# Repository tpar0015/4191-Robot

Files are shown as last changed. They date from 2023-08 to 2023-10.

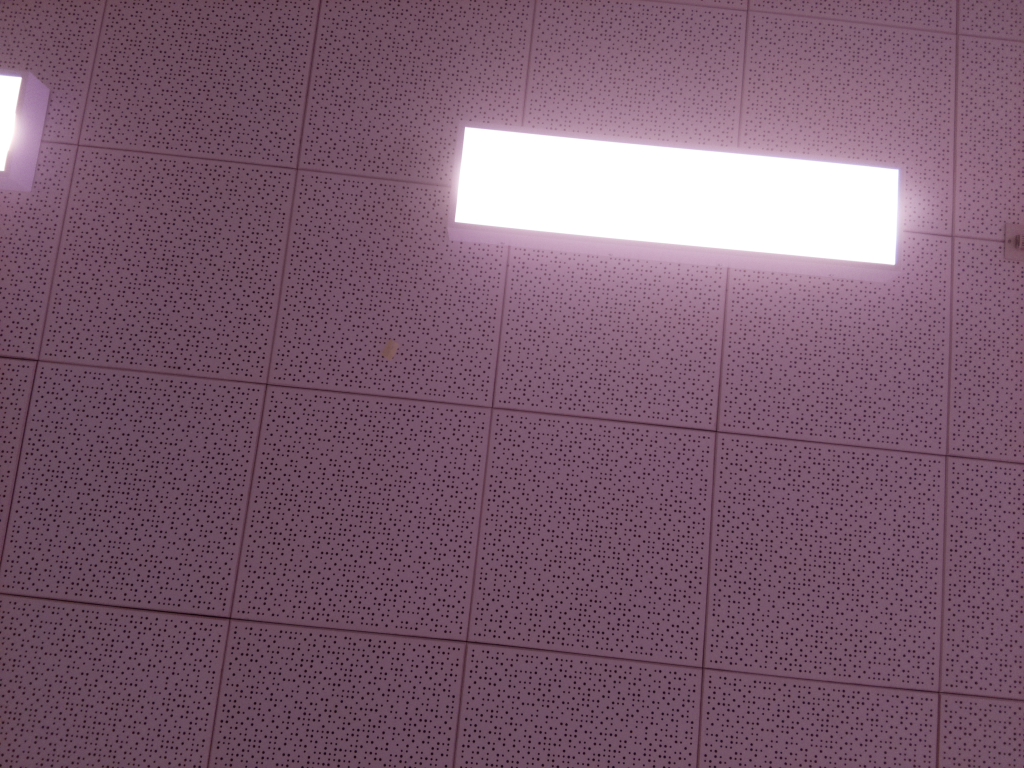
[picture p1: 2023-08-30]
camera_img/camera4.jpg

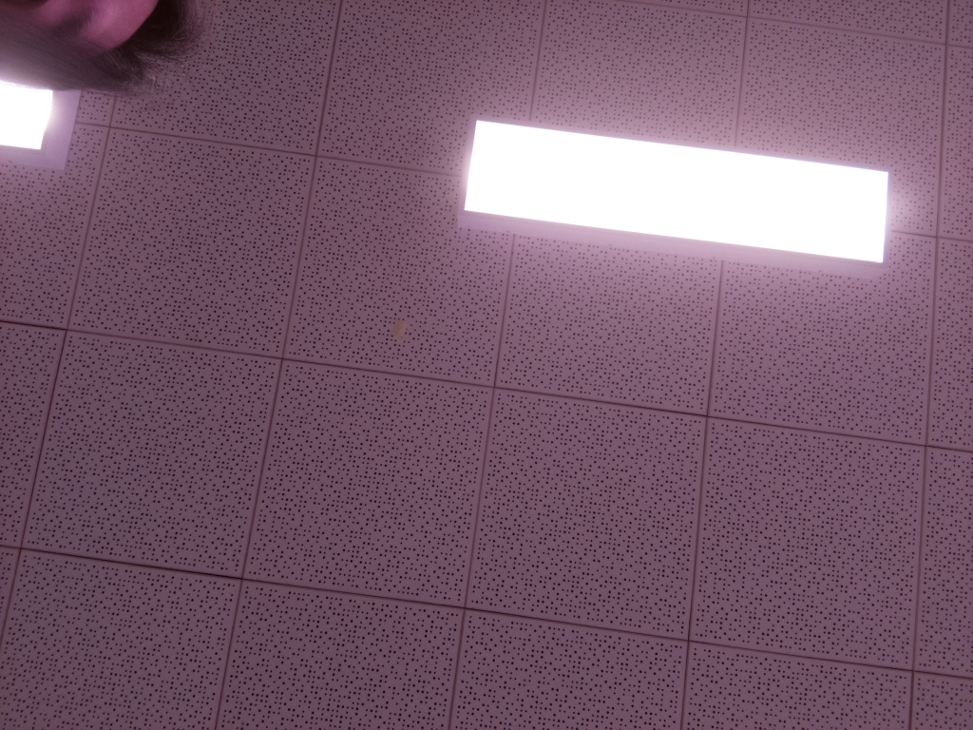
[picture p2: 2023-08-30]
camera_img/camera1.jpg

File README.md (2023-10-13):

# 4191-Robot

## Running loop

### 1. Load package

Robot should be in a safe state.

Needs to detect when package is loaded

### 2. Find target

Check sensors, apply computer vision if necessary.

Determine coordinates in warehouse.
    Possible method: find corners of the warehouse, centre for B and some angle for A/C. This relies on accuracy of robot placement and placement of bins

### 3. Aim

a. Aim horizontal

~~b. Aim vertical~~

c. Determine launch velocity

(confirm by checking sensors that target is centred)

### 4. Fire

Shoot projectile with predetermined parameters

### 5. Reset

Return to safe state

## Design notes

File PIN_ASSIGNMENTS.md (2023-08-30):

# Pin assignments

## Motors
BCM -- BOARD pin numbers
### Right motor
Fwd: 12 -- 32
Rev: 16 -- 36
EN: 6 -- 31

### Left motor
Fwd: 18 -- 12
Rev: 22 -- 15
EN: 27 -- 13

## Ultrasonic
Trig pin: 17
Echo pin: 20

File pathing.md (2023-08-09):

# 1. Localisation (localisation.py)

1. Consider immediately previous event.
    * Driving? Then robot is in middle of arena
    * Picked up box? Then robot is in the loading zone
    * Just delivered box? Then robot is in the delivery zone near A/B/C

2. Check sensor data

3. Convert sensor data to X,Y

4. Run navigation.py

# 2. Navigation (navigation.py)

0. Set up array of legal nodes (that are within the arena and NOT near any obstacles)

1. Check target destination
    * What's on the box? A/B/C

2. Check current location

3. Get target location

4. Run Dijkstra's algorithm

5. Run motor control
    * Generate motor inputs, pass to motorctl.py

6. IF arrived at delivery location, run loading.py
    * Pass LOAD or UNLOAD

# 3. Motor Control (motorctl.py) 

1. Get motor inputs

2. Translate to duty cycle for PWM

3. Apply to pins

# 4. Pickup/Delivery (loading.py)

0. If passed UNLOAD, goto 1; else if passed LOAD, goto 2

1. Unload
    * Turn toward wall
    * Tip out tray

2. Load
    * Turn away from wall
    * Raise tray

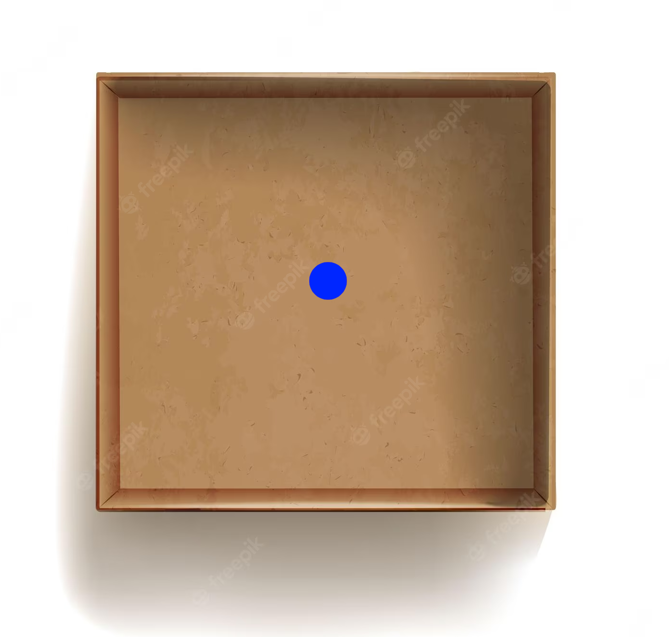
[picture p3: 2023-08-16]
package_detection/Blue/blue.png

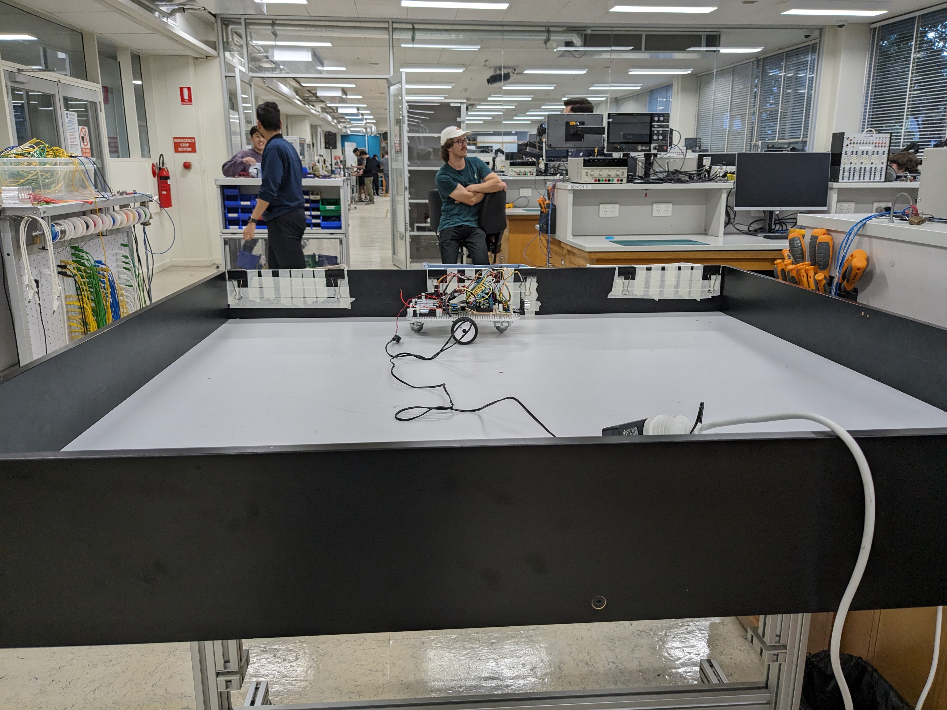
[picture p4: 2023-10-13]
Corner Detection/arena_tape_robot.jpg

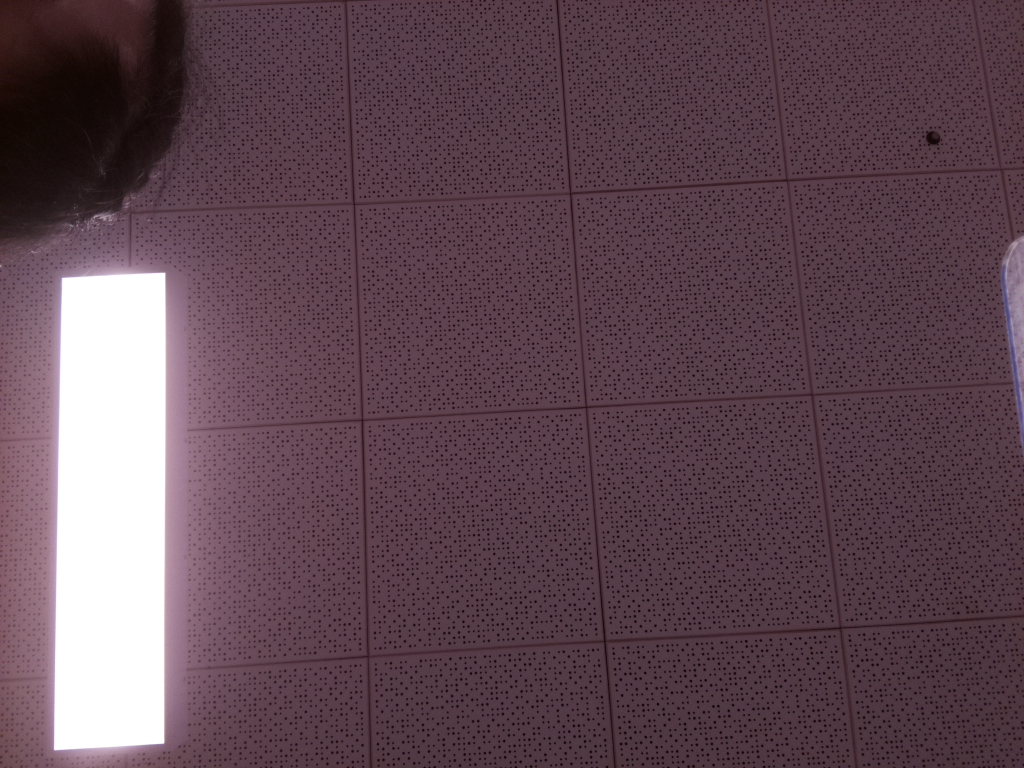
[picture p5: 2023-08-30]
camera_img/tes2/camera5.jpg

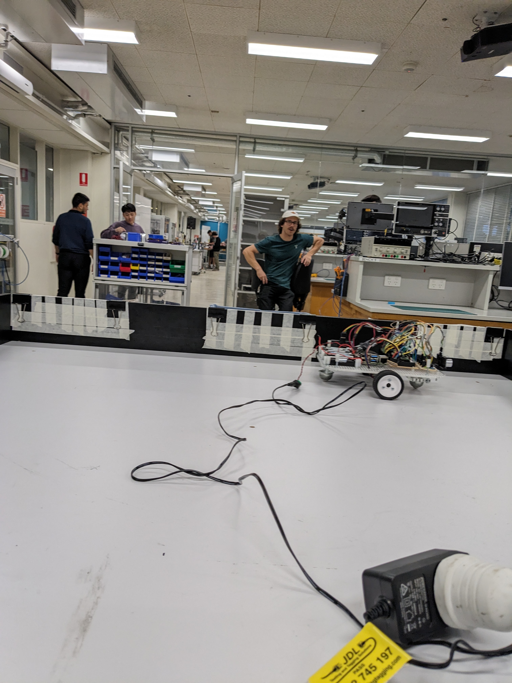
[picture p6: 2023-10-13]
Corner Detection/arena_tape_robot2.jpg

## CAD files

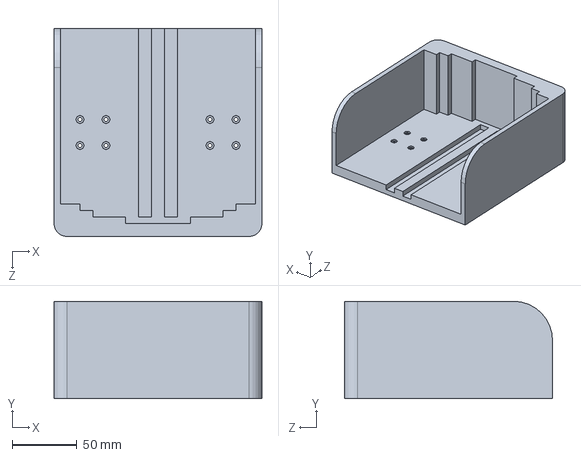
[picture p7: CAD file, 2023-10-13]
models/Drawback Assembly/package holder.SLDPRT
160.0 x 75.0 x 160.0 mm

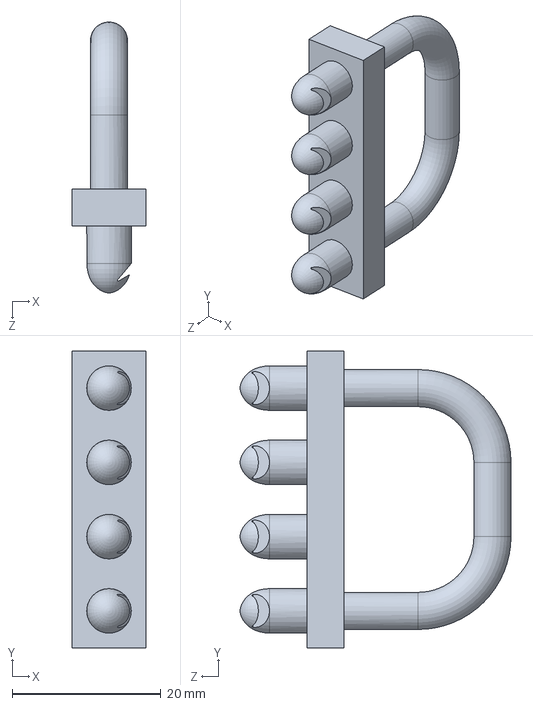
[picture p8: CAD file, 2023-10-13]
models/spring hook.SLDPRT
10.0 x 40.0 x 36.5 mm

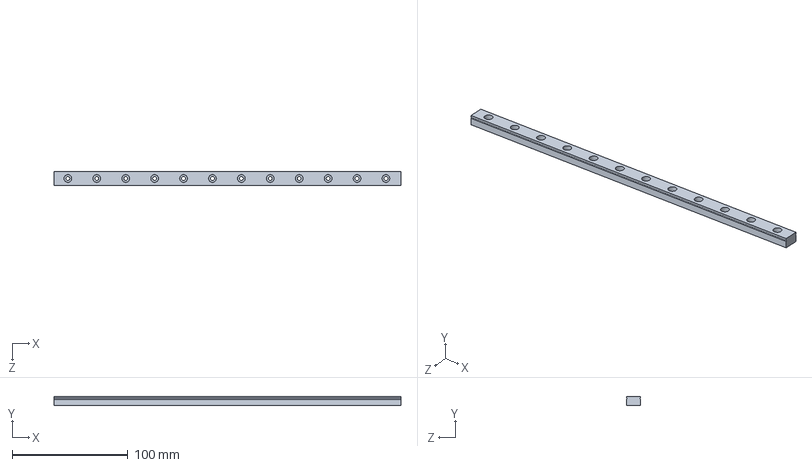
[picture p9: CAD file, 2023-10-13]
models/Drawback Assembly/linear_rail.SLDPRT
300.0 x 8.00 x 12.0 mm

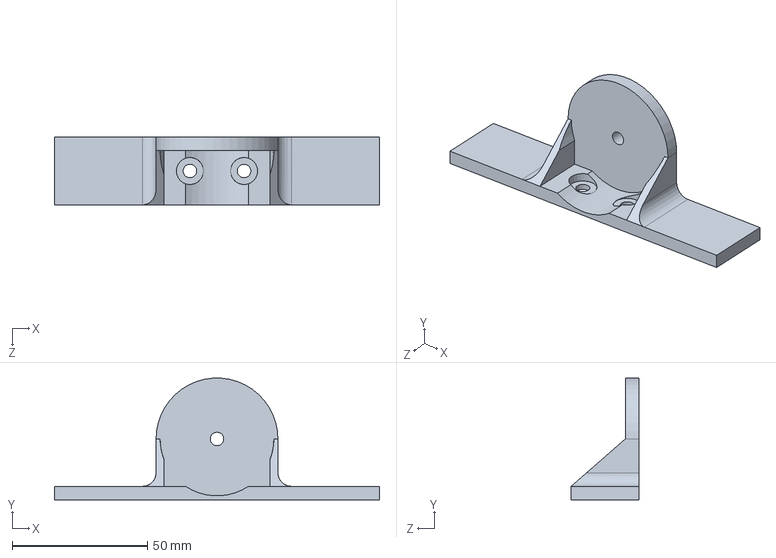
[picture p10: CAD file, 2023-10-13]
models/electromagnet holder.SLDPRT
120.0 x 44.9 x 25.0 mm

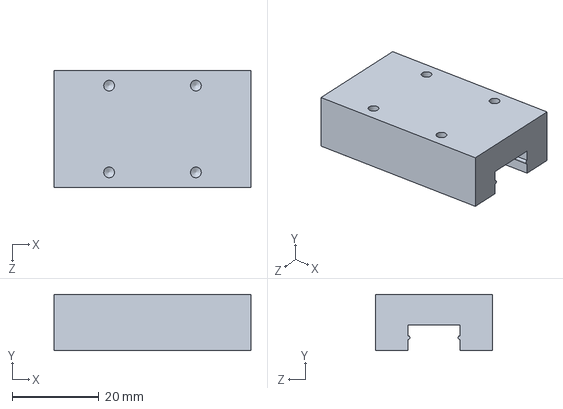
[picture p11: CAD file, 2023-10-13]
models/Drawback Assembly/linear bearing.SLDPRT
45.4 x 13.0 x 27.0 mm

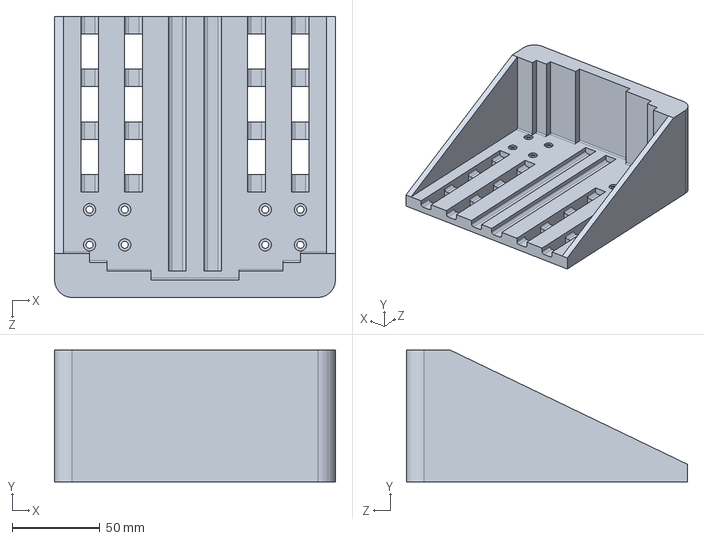
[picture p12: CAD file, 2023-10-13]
models/package holder.SLDPRT
160.0 x 75.0 x 160.0 mm

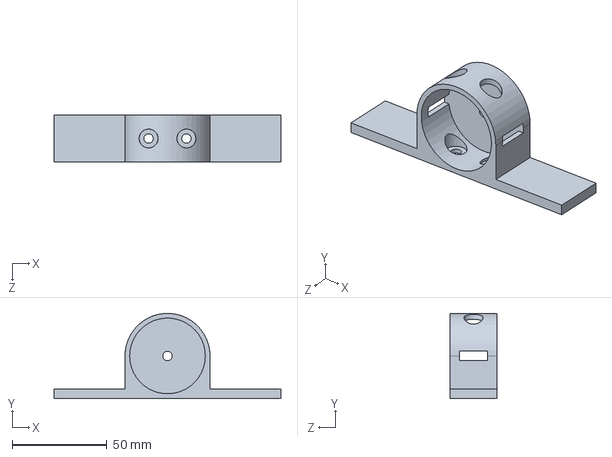
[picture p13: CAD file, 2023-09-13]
models/Drawback Assembly/electromagnet holder.SLDPRT
120.0 x 44.9 x 25.0 mm

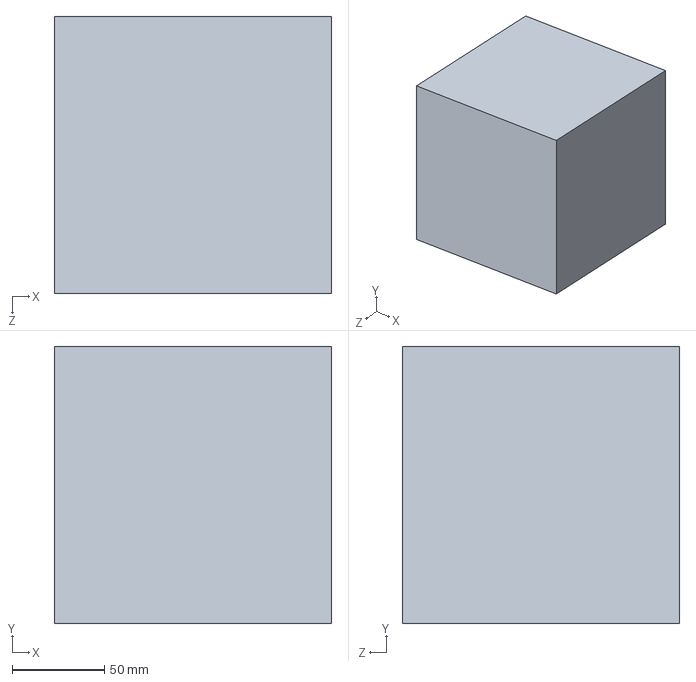
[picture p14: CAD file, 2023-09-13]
models/Drawback Assembly/package.SLDPRT
150.0 x 150.0 x 150.0 mm

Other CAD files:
models/Drawback Assembly/Assem1.SLDALASM.SLDDRW
models/electromagnet holder.STL
models/package holder.STL
models/spring hook.STL

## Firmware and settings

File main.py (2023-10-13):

## Main running loop for the package delivery robot
## Implements a state machine with two states: 'Load' and 'Fire'
from electromagnet import Electromagnet
from MotorControl.motorctl_new import Motor
from MotorControl.rotary_new import RotaryEncoder
from MotorControl.drive_test_final import Drive
from multiprocessing import Queue, Process
from pins import *
from load import load
from time import sleep
from aiming import aiming, turning_angle
import numpy as np

"""
Main Procedure:
1. Load Robot 
2. Put colour in front to detect Colour
3. Use colour to determine pullback and aiming angle
4. Use motor and electromagnet to drawback
5. Pivot to angle
6. Shoot
7. Repeat from 1
"""

def aim_shoot(robot_pose, color_sticker="red"):
    ##! Load cycle
    #input("Continue to run load")
    load(mag, launcher)
    
    ##! Fire cycle
    # Orient toward the target
    motor = Motor(PINS["motor1_en"], PINS["motor1_a"], PINS["motor1_b"])
    test_queue = Queue()
    robot_control = Drive(robot_pose, test_queue)
    
    input("Continue to run aiming")
    aiming(mag, motor, robot_control, robot_pose, color_sticker)

    # Reset
    # Change current pose depending on sticker
    robot_pose = [0,0,color_sticker]
    sleep(10)



if __name__== "__main__":
    # initialise electromagnet, electromagnet drawback motor
    mag = Electromagnet()
    launcher = Motor(PINS["motor1_en"], PINS["motor1_a"], PINS["motor1_b"], speed=100)

    # initialise wheels
    #wheel_left = Motor(PINS["motor1_en"], PINS["motor1_a"], PINS["motor1_b"], speed=100)
    #wheel_right = Motor(PINS["motor2_en"], PINS["motor2_a"], PINS["motor2_b"], speed=100)
    encoder_left = RotaryEncoder(PINS["encoder1_a"], PINS["encoder1_b"])
    encoder_right = RotaryEncoder(PINS["encoder2_a"], PINS["encoder2_b"])

    # Package 1 (smallest): Red
    # Package 2 (middle): Green
    # Package 3 (large): Blue

    """
    Aiming
    robot_pose = -1(left), 0(center), 1(right)
    color_sticker = -1(red), 0(blue), 1(green)
    color_sticker - robot_pose = 0 (don't turn), < 0 (turn right), > 0 (turn left)
    """
    robot_pose = [0,0,0]

    ### Without colour detector, reload and shoot in middle
    while True:
        # Check current colour for destination
        color_sticker = "red"#get colour output
        ##! Load cycle
        #input("Continue to run load")
        load(mag, launcher)
        
        
        ##! Fire cycle
        # Orient toward the target
        motor = Motor(PINS["motor1_en"], PINS["motor1_a"], PINS["motor1_b"])
        test_queue = Queue()
        robot_control = Drive(robot_pose, test_queue)
        
        input("Continue to run aiming")
        aiming(mag, motor, robot_control, robot_pose, color_sticker)

        # Reset
        # Change current pose depending on sticker
        robot_pose = [0,0,color_sticker]
        sleep(10)
    


'''
    ### With Colour Detection
    kernel = np.ones((5,5),np.uint8) # kernal is used for filter 
    cap = cv2.VideoCapture(0) # cv video capture
    sleep(0.5)

    # window size default change 
    cap.set(3,320)
    cap.set(4,240)
    # windows
    cv2.namedWindow('closing')
    cv2.namedWindow('tracking')

    while True:
        _, frame = cap.read()

        # HSV
        hsv = cv2.cvtColor(frame,cv2.COLOR_BGR2HSV)
        hue,sat,val = cv2.split(hsv)

        # get red color info
        # In HVS red blue and green is 3 distinct color and ease to distinguish colors
        hmn_r = 0
        hmx_r = 10
        smn_r = 50
        smx_r = 255
        vmn_r = 50
        vmx_r = 255

        hmn_b = 100
        hmx_b = 140
        smn_b = 50
        smx_b = 255
        vmn_b = 50
        vmx_b = 255

        hmn_g = 40
        hmx_g = 80
        smn_g = 50
        smx_g = 255
        vmn_g = 50
        vmx_g = 255
        # RED

        # apply and check if frame is in the range
        hthresh_red = cv2.inRange(np.array(hue),np.array(hmn_r),np.array(hmx_r))
        sthresh_red = cv2.inRange(np.array(sat),np.array(smn_r),np.array(smx_r))
        vthresh_red = cv2.inRange(np.array(val),np.array(vmn_r),np.array(vmx_r))

        # using bitwise and to combine all filterd result
        tracking_red = cv2.bitwise_and(hthresh_red,cv2.bitwise_and(sthresh_red,vthresh_red)) 

        # Blue  
        hthresh_blue = cv2.inRange(np.array(hue),np.array(hmn_b),np.array(hmx_b))
        sthresh_blue = cv2.inRange(np.array(sat),np.array(smn_b),np.array(smx_b))
        vthresh_blue = cv2.inRange(np.array(val),np.array(vmn_b),np.array(vmx_b))

        # using bitwise and to combine all filterd result
        tracking_blue = cv2.bitwise_and(hthresh_blue,cv2.bitwise_and(sthresh_blue,vthresh_blue)) 

        # Green
        hthresh_green = cv2.inRange(np.array(hue),np.array(hmn_g),np.array(hmx_g))
        sthresh_green = cv2.inRange(np.array(sat),np.array(smn_g),np.array(smx_g))
        vthresh_green = cv2.inRange(np.array(val),np.array(vmn_g),np.array(vmx_g))

        # using bitwise and to combine all filterd result
        tracking_green = cv2.bitwise_and(hthresh_green,cv2.bitwise_and(sthresh_green,vthresh_green)) 

        # filter red
        dilation = cv2.dilate(tracking_red,kernel,iterations = 1)
        closing = cv2.morphologyEx(dilation, cv2.MORPH_CLOSE, kernel)
        closing = cv2.GaussianBlur(closing,(5,5),0)
        circles_red = cv2.HoughCircles(closing,cv2.HOUGH_GRADIENT,2,150,param1=150,param2=70,minRadius=20,maxRadius=60)
        

        # filter blue
        dilation = cv2.dilate(tracking_blue,kernel,iterations = 1)
        closing = cv2.morphologyEx(dilation, cv2.MORPH_CLOSE, kernel)
        closing = cv2.GaussianBlur(closing,(5,5),0)
        circles_blue = cv2.HoughCircles(closing,cv2.HOUGH_GRADIENT,2,150,param1=150,param2=70,minRadius=20,maxRadius=60)

        # filter green
        dilation = cv2.dilate(tracking_green,kernel,iterations = 1)
        closing = cv2.morphologyEx(dilation, cv2.MORPH_CLOSE, kernel)
        closing = cv2.GaussianBlur(closing,(5,5),0)
        circles_green = cv2.HoughCircles(closing,cv2.HOUGH_GRADIENT,2,150,param1=150,param2=70,minRadius=20,maxRadius=60)


        detect_color = None
        # color detected and draw iin the window
        if circles_red is not None:
            detect_color = "red"
            print("red")
            # x, y, r = circles_red[0][0]
            # x_p = int(round(x))
    
            # for i in circles_red[0,:]:
                    
            #         if int(round(i[2])) < 30:
            #                 cv2.circle(frame,(int(round(i[0])),int(round(i[1]))),int(round(i[2])),(0,255,0),5)
            #                 cv2.circle(frame,(int(round(i[0])),int(round(i[1]))),2,(0,255,0),10)
                    
            #         elif int(round(i[2])) > 35:
            #                 cv2.circle(frame,(int(round(i[0])),int(round(i[1]))),int(round(i[2])),(0,0,255),5)
            #                 cv2.circle(frame,(int(round(i[0])),int(round(i[1]))),2,(0,0,255),10)
        elif circles_blue is not None:
            detect_color = "blue"
            print("blue")
        elif circles_green is not None:
            detect_color = "green"
            print("green")
        else:
            print("None")
        #cv2.imshow('closing',closing)
        cv2.imshow('tracking',frame)

        if detect_color != None:
            aim_shoot(robot_pose, color_sticker=detect_color)

        if cv2.waitKey(1) & 0xFF == ord('q'):
            cap.release()
            cv2.destroyAllWindows() 
            break

    cap.release()
    cv2.destroyAllWindows() 
'''

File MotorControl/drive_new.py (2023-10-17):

import sys
import time
import RPi.GPIO as GPIO

import numpy as np
import math
sys.path.append("/home/tom/4191-Robot/")
from MotorControl.motorctl_new import Motor
from pins import *
from multiprocessing import Manager
from processing import MultiProcess
class Drive:
    def __init__(self, pose):
        self.right_motor = Motor(PINS["motor1_en"], PINS["motor1_a"], PINS["motor1_b"])
        self.left_motor = Motor(PINS["motor2_en"], PINS["motor2_a"], PINS["motor2_b"])
        self.manager = Manager
        self.rotary_process = MultiProcess(self.manager)
        self.rotary_process.start_processes(ultrasonic=False)
        self.turn_radius = 110
        self.wheel_radius = 0.0524 * 1000  # Metres
        self.distance_per_tick = (self.wheel_radius * 2 * math.pi) / (74.83 * 48)  # Distance per tick in metres
        self.speed = 100
        self.pose = pose
        self.left_ticks = 0
        self.right_ticks = 0


    def set_ticks(self, left_ticks, right_ticks):
        self.left_ticks = left_ticks
        self.right_ticks = right_ticks
    def get_ticks(self):
        return self.rotary_process.get_rotary()
    def set_speed(self, speed):
        self.speed = speed

    def turn(self, theta):
        """Turns robot left by theta radians"""
        self.stops_by_speed()
        # Calculate number of ticks to turn
        turn_distance = abs(theta) * self.turn_radius
        num_ticks = turn_distance / self.distance_per_tick

        if theta > 0:
            left_speed = -self.speed
            right_speed = self.speed
        else:
            left_speed = self.speed
            right_speed = -self.speed

        # Do Turn
        self.control(num_ticks, left_speed, right_speed)
        
        self.left_motor.stop()
        self.right_motor.stop()

        # Check Ticks
        left_ticks, right_ticks = self.get_ticks()
        sum_ticks = left_ticks + right_ticks
        # Update Pose
        if theta > 0:
            self.pose[2] += sum_ticks * self.distance_per_tick / self.turn_radius
        else:
            self.pose[2] -= sum_ticks * self.distance_per_tick / self.turn_radius

        
    def drive_forward(self, distance):
        """Drives robot forward by distance"""
        assert distance > 0, "Distance must be positive"
        # Stop Motors
        self.stops_by_speed()
        # Set forward both motors
        left_speed, right_speed = self.speed, self.speed
        # Calculate number of ticks to drive
        num_ticks = 2 * distance / self.distance_per_tick
        print("====Forward====")
        print("sum ticks: ", self.get_left_ticks() + self.get_right_ticks())
        print("Drive Ticks: ", num_ticks)
        time.sleep(2)
        # Run Motors
        self.control(num_ticks, left_speed, right_speed)
        self.left_motor.stop()
        self.right_motor.stop()
        # Check Ticks
        left_ticks, right_ticks = self.get_ticks()
        # Update Pose
        tick_sum = left_ticks + right_ticks
        measure_distance = tick_sum * self.distance_per_tick / 2
        # Print
        print("=== Forward - Update Pose ===")
        print("Theta: ", self.pose[2])
        time.sleep(2)
        self.pose[0] += measure_distance * math.cos(self.pose[2])
        self.pose[1] += measure_distance * math.sin(self.pose[2])

    def drive_backward(self, distance):
        """Drives robot backward by distance"""
        
        assert distance > 0, "Distance must be positive"
        self.stops_by_speed()
        time.sleep(0.1)

        # Set backward both motors
        left_speed, right_speed = -self.speed, -self.speed

        num_ticks = distance / self.distance_per_tick

        self.control(num_ticks, left_speed, right_speed)
        self.left_motor.stop()
        self.right_motor.stop()
        left_ticks, right_ticks = self.get_ticks()

        tick_sum = left_ticks + right_ticks
        measure_distance = tick_sum * self.distance_per_tick / 2

        self.pose[0] -= measure_distance * math.cos(self.pose[2])
        self.pose[1] -= measure_distance * math.sin(self.pose[2])

    def stops_by_speed(self):
        self.left_motor.stop()
        self.right_motor.stop()

    def reset_encoders(self):
        self.set_ticks(0,0)
    def control(self, num_ticks, left_speed, right_speed):
        """Drives motors for num_ticks at speed, with PID tuning"""
        left_ticks, right_ticks = self.get_ticks()
        print("===Control===")
        print(f"left_ticks: {left_ticks}, right_ticks: {right_ticks}")
        time.sleep(2)
        print("Number of Ticks: ", num_ticks)
        print("Starting...")
        time.sleep(1)
        # While num_ticks not reached
        while (left_ticks + right_ticks) < num_ticks:
            self.right_motor.set_speed(right_speed)
            self.left_motor.set_speed(left_speed)
            left_ticks,right_ticks = self.get_ticks()
    def drive_to_point(self, x, y, theta_end=None):
        """Drives robot to point (x, y)"""
        dx = x - self.pose[0]
        dy = y - self.pose[1]
        
        theta = math.atan2(dy, dx) # the angle between cur_poos to des
        print("cal check : ", "dx:  ", dx, "dy: " , dy, "theta : ", theta)
        print("=====Start Turn=====")
        print("===Theta===: ", theta)
        
        input("check")
        time.sleep(2)
        if abs(theta) > np.pi/16:
            self.turn(theta)
        distance = math.sqrt(dx**2 + dy**2)
        if distance == 0:
            print("At Point")
            return
        input("Check")
        time.sleep(0.1)
        self.drive_forward(distance)
        if theta_end is not None:
            # Difference in angle between current and desired
            theta_diff = theta_end - self.pose[2]
            if theta_diff > np.pi/16:
                self.turn(theta_diff)
        # Adds pose to queue
        self.queue.put(self.get_pose())
    def get_pose(self):
        return self.pose

    def clean(self):
        GPIO.cleanup()

if __name__== "__main__":
    robot_control = Drive([0,0,np.pi/2])
    try:


        theta = -np.pi
        robot_control.turn(theta)
        print("second round")
        time.sleep(2)
        
        theta = np.pi
        robot_control.turn(theta)

        

        


        input("c")
        robot_control.drive_to_point(200,200,None)
    except Exception as e:
        print(e.args)
    GPIO.cleanup()

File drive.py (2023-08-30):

# This file will provide functions to determine motor inputs
# given the robot's current position and [x,y] array of target waypoints

import numpy as np
import motorctl

Robot = motorctl.Motor()

# angle = None
# speed = None


# waypoints = []
# position = []

def drive(waypoints, position, speed, angle):
    # angle = arctan(diff_y/diff_x) adjusted for Q2, Q3 of unit circle
    diff_y = waypoints[0][1] - position[1]
    diff_x = waypoints[0][0] - position[0]
    target_angle = np.arctan2(diff_y, diff_x)

    angle_deviation = target_angle - angle

    # distance = sqrt(diff_x^2 + diff_y^2)
    distance = np.sqrt(sum(np.power([diff_x, diff_y], 2)))

    # turn to the target angle
    if angle_deviation > 0:
        # turn left to the angle
        Robot.spin_left(0.6)
        #? stop turning when angle is reached
        
    else:
        # turn right to the angle
        Robot.spin_right(0.6)
        #? stop turning when angle is reached

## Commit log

2023-08-08 Motor control code
    Set parameters for motor control. Still need to add functionality of setting RasPi pin values.
2023-08-08 Added code for PWM control
    Figured it out
2023-08-09 Motor test 1
    Testing the functionality of motor using R pi 4
2023-08-14 Fleshed out running loop. Need to know motors used
2023-08-14 Initialise camera
2023-08-15 Updated code for motor control and rotary encoder
2023-08-16 untested code for ultrasonic sensor
2023-08-16 motor test script
2023-08-16 lowered PWM freq
2023-08-16 Reordered conditions for motor control
2023-08-20 Completed ultrasonic sensor module
2023-08-20 Fixed bug in ultrasonic module
    [ultrasonic.py]
2023-08-20 ultrasonic is tested perfect, motor control is not tested yet
2023-08-23 Updated rotary encoder code
2023-08-23 changed pins for rotary encoder
2023-08-26 Revert "Merge branch 'main' of https://github.com/tpar0015/4191-Robot"
    This reverts commit 245c80f5b6897561bb85eeb4a5282f8a49cc29ee, reversing
    changes made to 04fc1318853876bb7ee96b6a83641bab49f616ab.
    [corner_detection.py, rotary.py]
2023-08-26 Revert "Revert "Merge branch 'main' of https://github.com/tpar0015/4191-Robot""
    This reverts commit f1bc5c5b12ea42545b887c76d133a785589c0ff9.
    [corner_detection.py, rotary.py]
2023-08-26 robot sample procedure (incomplete)
2023-08-29 Added document to track pin assignments, untested code to drive the robot
2023-08-29 additional sample images of obstacles/arena
2023-08-29 additional sample images of the arena/obstacles
2023-08-29 random sample obstacle avoidance code (improvements and change driving needed)
2023-08-29 Changed pin assignments
2023-08-29 motor ctl update
2023-08-30 update motor
2023-08-30 Changed pin numberings
2023-08-30 Renamed to new motorctl file
2023-08-30 Update ceiling.py base on the image taken from camera
2023-08-30 camera capture code
2023-08-30 Added new motor control, rotary encoder and drive function
2023-08-30 updated with sample camera process
2023-08-31 Commenting out the print statements some files.
2023-08-31 updated pin numbers
2023-09-12 Added Solidworks models for package and electromagnet holder.
    Need to add attachment points to rails and bearings.
    [electromagnet holder.SLDPRT, package holder.SLDPRT, package.SLDPRT]
2023-09-13 Adjusted CAD files for holders. Should be usable.
    [electromagnet holder.SLDPRT, package holder.SLDPRT]
2023-09-13 Reduced extension of back plate width adjustments.
    [package holder.SLDPRT]
2023-09-13 Added flanges to electromagnet holder
    These should be sitting on top of the rails preventing the electromagnet from spinning with the screw.
    [electromagnet holder.SLDPRT, package holder.SLDPRT]
2023-09-13 added frequency to pwm electromagnet
2023-09-13 Made some STLs for printing.
    Seems the package holder needs 21 hours to print. Troubling.
    [electromagnet holder.SLDPRT, electromagnet holder.STL, package holder.SLDPRT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]
2023-09-18 Added solidworks assembly of drawback system
    [Assem1.SLDALASM.SLDDRW, electromagnet holder.SLDPRT, linear bearing.SLDPRT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]
2023-09-20 Spring hook
    [spring hook.SLDPRT, spring hook.STL]
2023-09-20 Revised electromagnet holder
    [electromagnet holder.SLDPRT, electromagnet holder.STL]
2023-09-21 Updated package holder file for faster print, moved screw holes
    [package holder.SLDPRT, package holder.STL]
2023-09-26 Updated models
    [package holder.SLDPRT, package holder.STL]
2023-10-03 Initialising wheels, test code for launcer
2023-10-07 Electromagnet control circuit is now active low
2023-10-07 Comment to indicate reasons for inverted logic
    [electromagnet.py]
2023-10-09 Motor controller ciccuit
2023-10-10 Create colorCircles.py
    camera color circle detect
2023-10-16 Added power board design
2023-10-16 Added png version of powerboard
2023-10-16 calibration update
2023-10-16 pin changes, slight processor changes
2023-10-17 Commented out code not working yet
    [test_main.py]
2023-10-17 Fixed error in coordinate convention
    [test_main.py]
2023-10-17 removed pid
2023-10-17 New veroboard circuit to replace two motor drivers
